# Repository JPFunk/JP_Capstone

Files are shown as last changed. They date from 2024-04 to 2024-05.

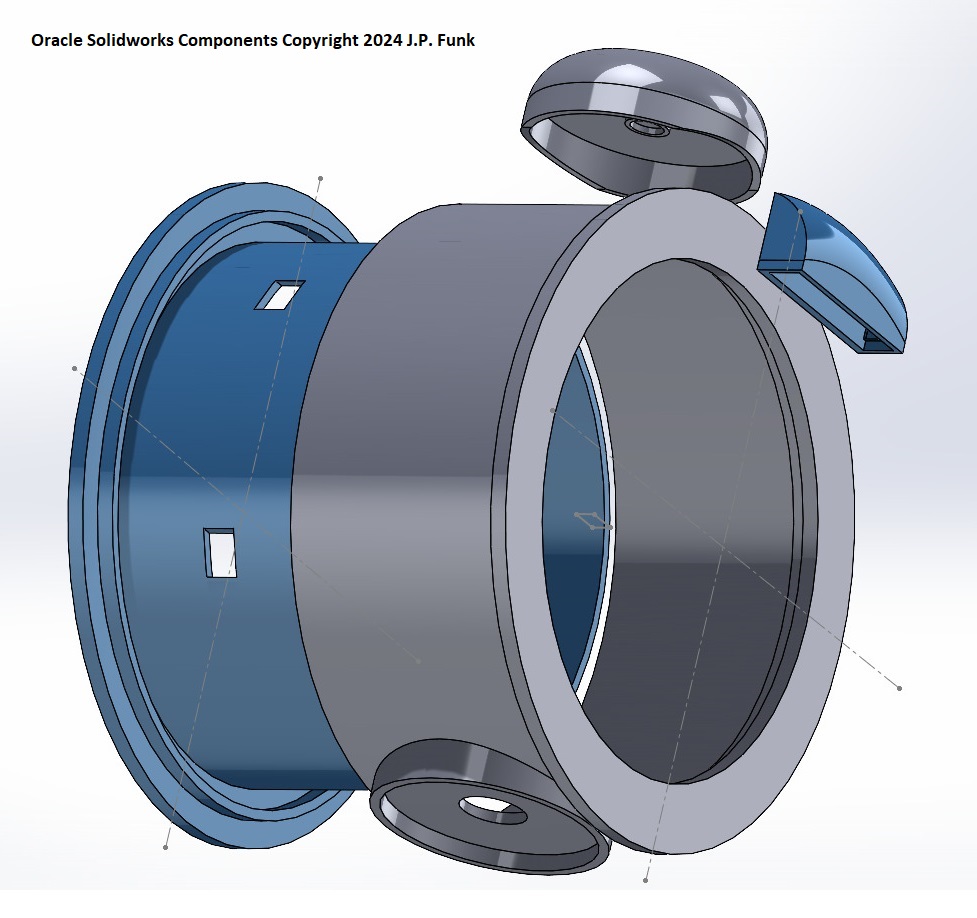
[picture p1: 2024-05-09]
JP_Capstone_Support_Files/JP_Capstone_3D/JP_Oracle_Solidworks/JP_Oracle_Assembly_Ring.JPG

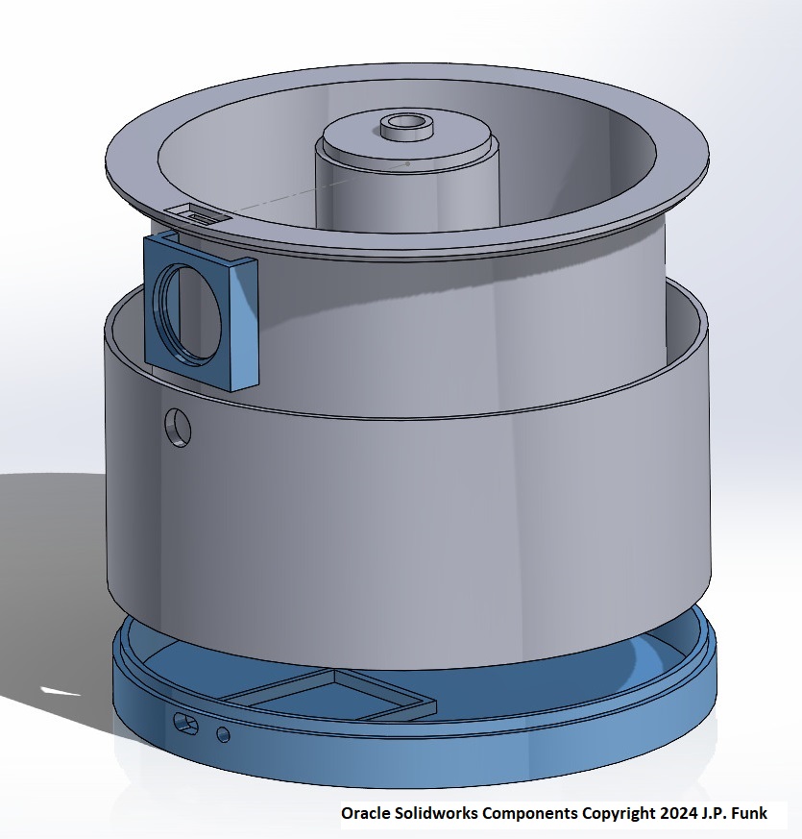
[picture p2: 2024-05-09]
JP_Capstone_Support_Files/JP_Capstone_3D/JP_Oracle_Solidworks/JP_Oracle_Assembly_Base.JPG

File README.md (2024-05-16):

# JP_Oracle_Fountain
Project completeion date: 05/16/2024

Project Motivation and Overview:
The Oracle Fountain is a IoT smart indoor water feature with Lighting and Sound components that would create Tranquil and Relaxing Ambiance for interior spaces. The fountain has 3 main modes: Waterfall feature, Crystal Ball Lighting for atmosphere (nighttime) and Sound (Looping soundscapes), Environment BME sensor with internet dashboard control/connectivity.

Ativating the modes are simple and elegant: 
The touch sensor is hidden inside the housing with just a fingertip size hole to access the button and toggles the Waterfall On Off also activating NeoPixel Waterfall panel.
The ToF has 4 levels (modes) with corresponding Neopixel (x4) color changes with each toggle:
1. Level 1- Crystal Ball on (Cyan), Crystal Ball off (Yellow)
2. Level 2- MP3 Player Tracks on (Turqoise) tracks off (Magenta)
3. Level 3- MP3 Player Volume on (Blue) tracks off (Green)
4. Level 4- Neopixels Off (for dark or stealth usage)

Control Features:
  • Waterfall pump, Music/Soundscapes and LED light show
  • Adafruit.IO Dashboard connection and functions
  • Touch button control for Waterfall and TOF: MP3 tracks, Volume and Turn off NeoPixels

Entertainment Features:
  •  MP3 player with speaker (Soundscapes)
  •  Crystal Ball with Neopixels
  •  Waterfal w/ Backlit Laser etched panel

Components: 
  • Argon processor, small board, BME sensor, ToF (Time of Flight) sensor, water pump, relay, neopixels (5) & ring, Touch Sensor, push button, MP3 w/ Speaker 
  • 3D Printed sections: Base, top ring, LED module (top) 10 parts total
  • Electrical wiring, power supply (usb)
  • Waterfall components: Tubing,  water diffusers 
  • Acrylic waterfall etched/cut panel
 
Other Information:
The Capstone design will be built to emphasis IoT features, the MVP production version will be refit with minimum E-components to accommodate a Starter Model not requiring P2 programming/connection.

Stretch Goal Features:
  • Phone App subscription for sound loops and additional content *
  • Auto and Sleep Mode
  • Patent, and produce for market

Hackster.io page

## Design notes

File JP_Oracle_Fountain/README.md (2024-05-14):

# JP_Oracle_Fountain

Project Motivation and Overview:
The Oracle Fountain is a IoT smart indoor water feature with Lighting and Sound components that would create Tranquil and Relaxing Ambiance for interior spaces. The fountain would have 3 main modes: 2 Water (high, low) Levels, Lighting for atmosphere (nighttime) and Sound (Looping soundscapes), Environment sensor with internet dashboard control/connectivity.

Minimum Features:
  • Waterfall pump,  LED light show
  • Dashboard
  • Minimum button control TOF
  • 3D Printed Housing, with one upper waterfall ring

Desired Features:
  •  MP3 player with speaker
  •  3D Printed Housing, 1 upper waterfall ring
  •  Button less interface/controls (ToF)

Stretch Goal Features:
  • Phone App subscription for sound loops and additional content *
  • Auto and Sleep Mode
  • Patent, and produce for market

Anticipated Components:
  • *TOF sensors (at least 1), small board w/ P2, water pump, relay, neopixel ring  BME
  • 3D Printed sections: Base, top ring, LED module (top)
  • Waterfall components: Tubing, connectors, water diffusers 
  • Electrical wiring, power supply (s)

Concerns and Considerations (Project Risks and Potential Mitigation's)
  •  getting TOF sensors to work properly for controls
  •  3D printed housing functional for waterfall feature. *3D design will center around 3D Printing footprint (base printing size/area)
  •  Automated modes, sleep
  •  Dashboard/bluetooth/code-red functions

Other Information:
The Capstone design will be built to emphasis IoT features, the MVP  production version will be refit with minimum E-components to accommodate a Starter Model not requiring P2 programming/connection.

Hackster.io page

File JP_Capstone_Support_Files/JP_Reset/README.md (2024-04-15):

# JP_Reset

This firmware project was created using [Particle Developer Tools](https://www.particle.io/developer-tools/) and is compatible with all [Particle Devices](https://www.particle.io/devices/).

Feel free to replace this README.md file with your own content, or keep it for reference.

## Table of Contents
- [Introduction](#introduction)
- [Prerequisites To Use This Template](#prerequisites-to-use-this-repository)
- [Getting Started](#getting-started)
- [Particle Firmware At A Glance](#particle-firmware-at-a-glance)
  - [Logging](#logging)
  - [Setup and Loop](#setup-and-loop)
  - [Delays and Timing](#delays-and-timing)
  - [Testing and Debugging](#testing-and-debugging)
  - [GitHub Actions (CI/CD)](#github-actions-cicd)
  - [OTA](#ota)
- [Support and Feedback](#support-and-feedback)
- [Version](#version)

## Introduction

For an in-depth understanding of this project template, please refer to our [documentation](https://docs.particle.io/firmware/best-practices/firmware-template/).

## Prerequisites To Use This Repository

To use this software/firmware on a device, you'll need:

- A [Particle Device](https://www.particle.io/devices/).
- Windows/Mac/Linux for building the software and flashing it to a device.
- [Particle Development Tools](https://docs.particle.io/getting-started/developer-tools/developer-tools/) installed and set up on your computer.
- Optionally, a nice cup of tea (and perhaps a biscuit).

## Getting Started

1. While not essential, we recommend running the [device setup process](https://setup.particle.io/) on your Particle device first. This ensures your device's firmware is up-to-date and you have a solid baseline to start from.

2. If you haven't already, open this project in Visual Studio Code (File -> Open Folder). Then [compile and flash](https://docs.particle.io/getting-started/developer-tools/workbench/#cloud-build-and-flash) your device. Ensure your device's USB port is connected to your computer.

3. Verify the device's operation by monitoring its logging output:
    - In Visual Studio Code with the Particle Plugin, open the [command palette](https://docs.particle.io/getting-started/developer-tools/workbench/#particle-commands) and choose "Particle: Serial Monitor".
    - Or, using the Particle CLI, execute:
    ```
    particle serial monitor --follow
    ```

4. Uncomment the code at the bottom of the cpp file in your src directory to publish to the Particle Cloud! Login to console.particle.io to view your devices events in real time.

5. Customize this project! For firmware details, see [Particle firmware](https://docs.particle.io/reference/device-os/api/introduction/getting-started/). For information on the project's directory structure, visit [this link](https://docs.particle.io/firmware/best-practices/firmware-template/#project-overview).

## Particle Firmware At A Glance

### Logging

The firmware includes a [logging library](https://docs.particle.io/reference/device-os/api/logging/logger-class/). You can display messages at different levels and filter them:

```
Log.trace("This is trace message");
Log.info("This is info message");
Log.warn("This is warn message");
Log.error("This is error message");
```

### Setup and Loop

Particle projects originate from the Wiring/Processing framework, which is based on C++. Typically, one-time setup functions are placed in `setup()`, and the main application runs from the `loop()` function.

For advanced scenarios, explore our [threading support](https://docs.particle.io/firmware/software-design/threading-explainer/).

### Delays and Timing

By default, the setup() and loop() functions are blocking whilst they run, meaning that if you put in a delay, your entire application will wait for that delay to finish before anything else can run. 

For techniques that allow you to run multiple tasks in parallel without creating threads, checkout the code example [here](https://docs.particle.io/firmware/best-practices/firmware-template/).

(Note: Although using `delay()` isn't recommended for best practices, it's acceptable for testing.)

### Testing and Debugging

For firmware testing and debugging guidance, check [this documentation](https://docs.particle.io/troubleshooting/guides/build-tools-troubleshooting/debugging-firmware-builds/).

### GitHub Actions (CI/CD)

This project provides a YAML file for GitHub, automating firmware compilation whenever changes are pushed. More details on [Particle GitHub Actions](https://docs.particle.io/firmware/best-practices/github-actions/) are available.

### OTA

To learn how to utilize Particle's OTA service for device updates, consult [this documentation](https://docs.particle.io/getting-started/cloud/ota-updates/).

Test OTA with the 'Particle: Cloud Flash' command in Visual Studio Code or the CLI command 'particle flash'!

This firmware supports binary assets in OTA packages, allowing the inclusion of audio, images, configurations, and external microcontroller firmware. More details are [here](https://docs.particle.io/reference/device-os/api/asset-ota/asset-ota/).

## Support and Feedback

For support or feedback on this template or any Particle products, please join our [community](https://community.particle.io)!

## Version

Template version 1.0.2

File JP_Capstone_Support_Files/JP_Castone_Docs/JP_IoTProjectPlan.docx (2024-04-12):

Project Name: Oracle Fountain (wellness engine) Creation Date: April 10th, 2024
Student Name: JP Funk | | | Capstone Date: May 17th

Project Motivation and Overview:

The Oracle Fountain is a IoT smart indoor water feature with Lighting, Sound & Environmental components that would create Tranquil and Relaxing Ambiance for interior spaces. The fountain would have 3 main modes: 2 Water Flow: (high, low) Levels, *Lighting for atmosphere (Multi-modes nighttime) and *Sound (Looping soundscapes), Environment sensor with internet dashboard control/connectivity.

Minimum Features:

- Waterfall pump, LED light show, BME
- Dashboard
- minimum button control
- 3D Printed Housing, with one Stage waterfall ring

Desired Features:

- MP3 player with speaker
- 2 modes water flow
- 3D Printed Housing, with 2 stages waterfall rings
- Auto and Sleep Mode
- Button less interface/controls (ToF)

Stretch Goal Features:

- Phone App (subscription for sound loops and additional content *)
- Patent, and produce for market

Anticipated Components:

- *TOF sensors (at least 1), small board w/ P2, water pump, relay, neopixel ring *OLED, BME, *Encoder
- 3D Printed sections: Base, lower ring, top ring, LED module (top)
- Waterfall components: Tubing, connectors, water diffusers
- Electrical wiring, power supply (s)

Concerns and Considerations (Project Risks and Potential Mitigation's)

- Getting TOF sensors to work properly for controls
- 3D printed housing functional for waterfall feature. *3D design will center around 3D Printing footprint (base printing size/area)
- Automated modes, sleep
- Dashboard/bluetooth/code-red functions

Other Information:

*OLED may/may not be used depending on design build.

The Capstone design will be built to emphasis IoT features, the MVP production version will be refit with minimum E-components to accommodate a Starter Model not requiring P2 programming/connection.

Project Implementation Timeline:
Tasks | 12-APR | 19-APR | 26-APR | 3-May | 10-May | 17-May
Project Plan | X | | | | | Presentation
JP_Capstone Oracle Fountain Daily work/production will logged on Calendar | Submit Project plan summary | Prototype case with TOF, starting code | Design and build 3D Waterfall housing | Write/implement code, testing, Debug | Create: Presentation Media, Video, Hackster.io etc. | Demo: Presentation Hackster Video Q/A
Hours per week/
Capstone Presentation | | | | | | X

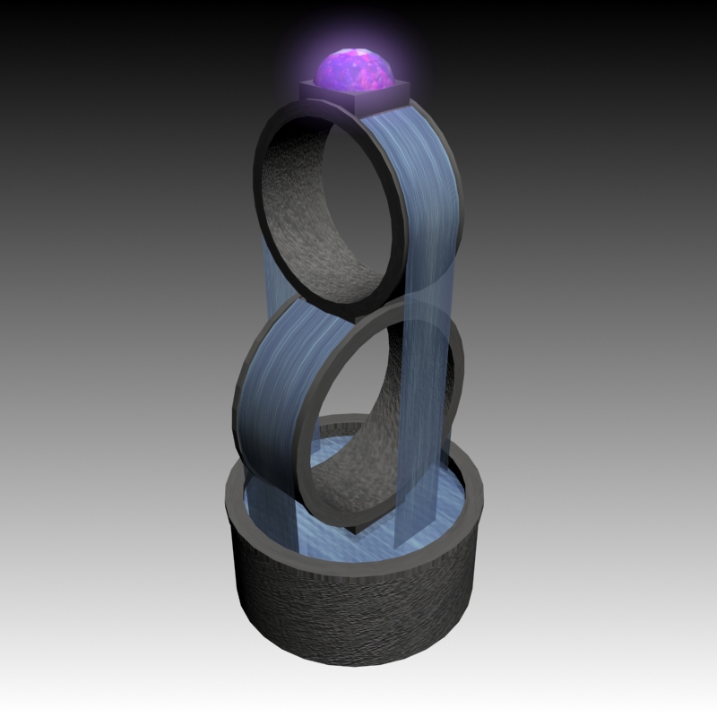
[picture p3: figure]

3D Render simple visualization concept: The base reservoir section (Bottom) will be designed to house the electrical components of the project with designated channels in the base (bottom or a specific section of the side) to house the processor and board.

ToF, OLED, BME, Encoder etc. will be implemented inside electrical gaps/channels residing between the outer face/shell and water shell wall with cut outs (custom installation mounts) for these features. Similar implementation will be used to run the water tubing and wiring through the rings for LED, OLED, BME features etc.

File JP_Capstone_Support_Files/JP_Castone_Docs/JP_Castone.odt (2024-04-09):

JP Funk IoT Deep Dive Boot Camp Capstone Project submission: Oracle Fountain

The Oracle Fountain is a IoT smart indoor water feature with Lighting and Sound components that would create Tranquil and Relaxing Ambiance for interior spaces.

The fountain would have 3 main modes: 2 Water Pump/Speed (high, low) Levels, Lighting for atmosphere (nighttime) and Sound (Looping soundscapes).

The interface would be Elegant and simple: IR Range and Motion Sensors requiring no buttons or switches on the front panel that would detect and use proximity for activating the features.

Other Sensors could be implemented for environmental detection and awareness.

*The Sound module would ideally be loops that would require little bit of memory and would be in first Gen simplified into a few modes:

1. Bells/Gong

2. Chimes

3. Bowls

*4. Tongue Drum

The physical portion of the fountain would be build up from 3 main 3D Printed sections:

The Water/pump & Electronics Basin, the 1st vertical ring and a 2nd vertical ring (stacked up on top of each other).

The Oracle Fountain would sit in a room/space, offer 2 levels (high, low) of water flow, a nighttime light show and Looping soundscapes. *It could be remotely monitored and activated (either through Adafruit, BT and/or Node-Red etc.). The goal is to produce these as MVP for my entrepreneurial biz in short run (per customer order) then move up to larger production if product became an in demand commodity.

The Oracle has been an idea(concept) initially thought of a year ago during the Santa Fe Creative Startups 6 week class. A sound system prototype was built (Speaker box) and then evolved to a water feature with lighting. The sound system might later be implemented as a BlueTooth app with many sound and atmosphere features.

Can Do’s: Water Pump, LED (NeoPixels), motion sensor w/code- 3D Printing

Have not done yet: A very sophisticated Customized 3D Printed system w/ many watertight seals at connection joints, wiring, tubing, encased electronics & sound system.

IR sensors for touch less control (with code)- controlling water pump, LED and sound system integration with Loops. Possible room/environment observation.

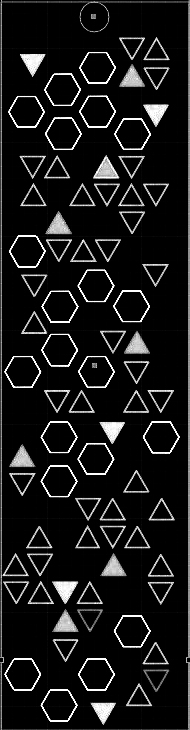
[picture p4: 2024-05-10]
JP_Capstone_Support_Files/JP_Capstone_3D/3D_Maps/JP_Oracle_WaterPane_Alpha.jpg

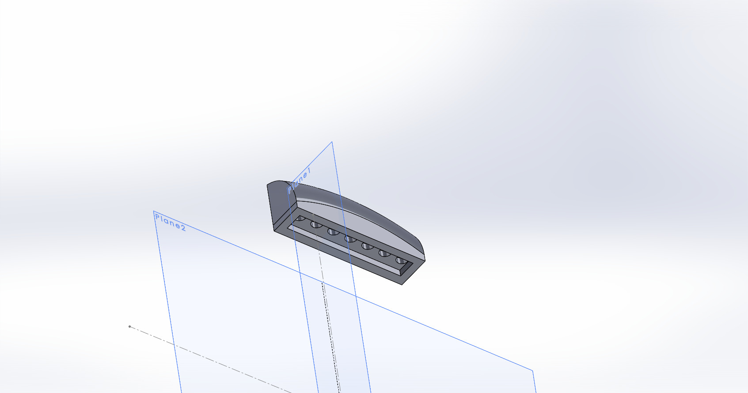
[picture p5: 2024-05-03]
JP_Capstone_Support_Files/JP_Capstone_3D/JP_Oracle_Solidworks/JP_Oracle_Top_Water_Shroud_Front.JPG

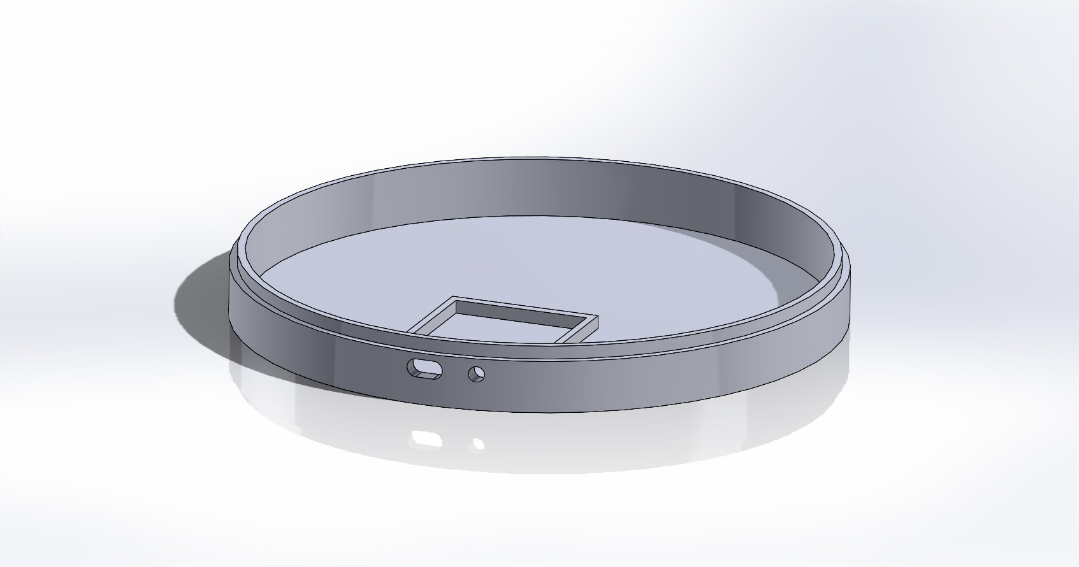
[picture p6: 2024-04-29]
JP_Capstone_Support_Files/JP_Capstone_3D/JP_Oracle_Solidworks/JP_Oracle_EBase.JPG

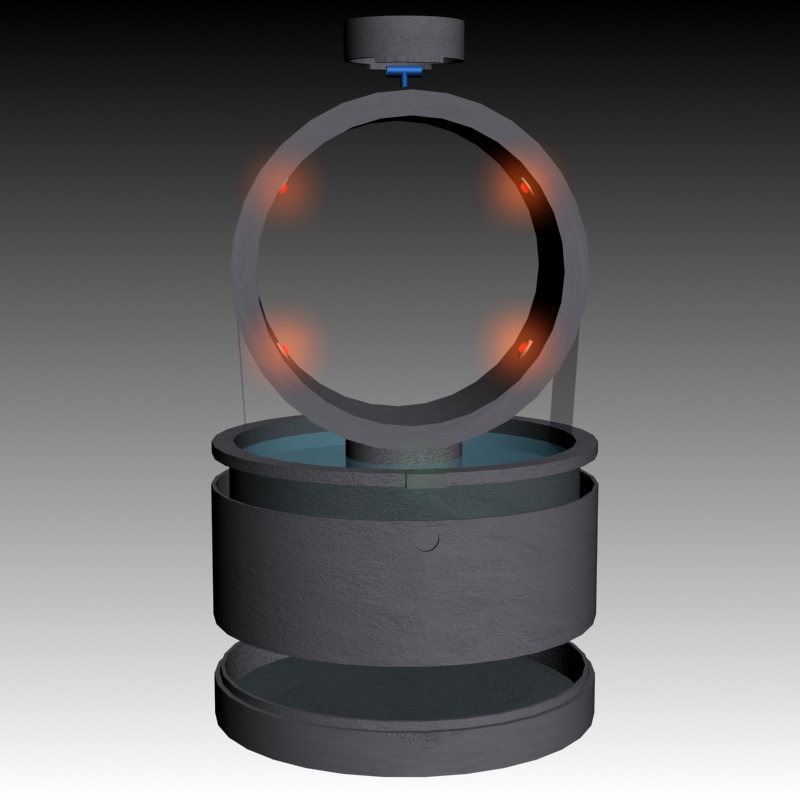
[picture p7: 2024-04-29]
JP_Capstone_Support_Files/JP_Capstone_3D/JP_Oracle_Explode_View.jpg

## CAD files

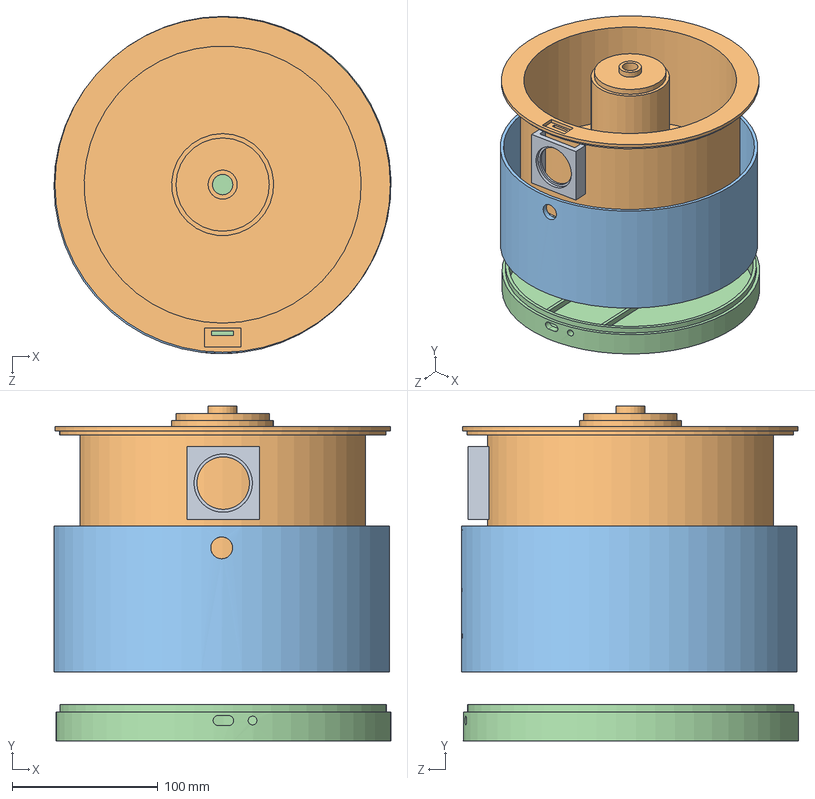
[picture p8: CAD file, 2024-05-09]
JP_Capstone_Support_Files/JP_Capstone_3D/JP_Oracle_Solidworks/JP_Oracle_Assembly_Base.SLDASM
231.1 x 229.7 x 231.3 mm
JP_Oracle_EBase
JP_Oracle_Base_Ring
JP_Oracle_Water_Basin
JP_Oracle_Speaker_Ring

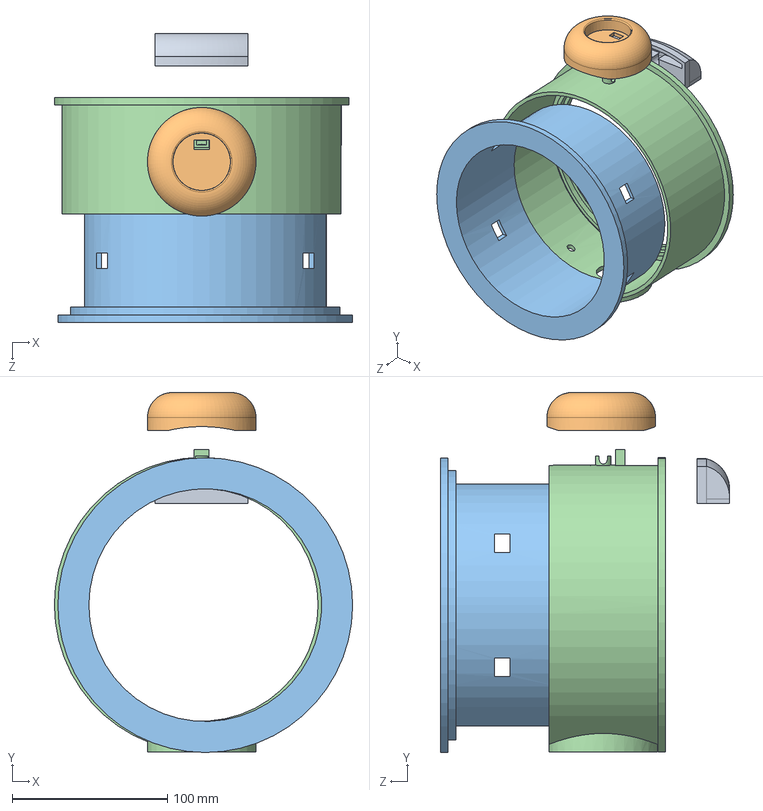
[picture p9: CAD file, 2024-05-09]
JP_Capstone_Support_Files/JP_Capstone_3D/JP_Oracle_Solidworks/JP_Oracle_Assembly_Ring.SLDASM
192.3 x 232.1 x 186.4 mm
JP_Oracle_Top_Ring_Outer
JP_Oracle_Top_Ring_inner
JP_Oracle_Top_Crystal
JP_Oracle_Top_Water_ShroudV2

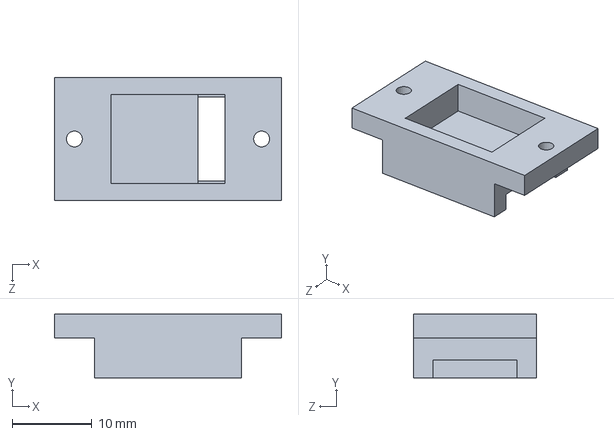
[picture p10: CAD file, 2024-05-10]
JP_Capstone_Support_Files/JP_Capstone_3D/JP_Oracle_Solidworks/JP_BME_Holder.SLDPRT
28.5 x 8.00 x 15.5 mm

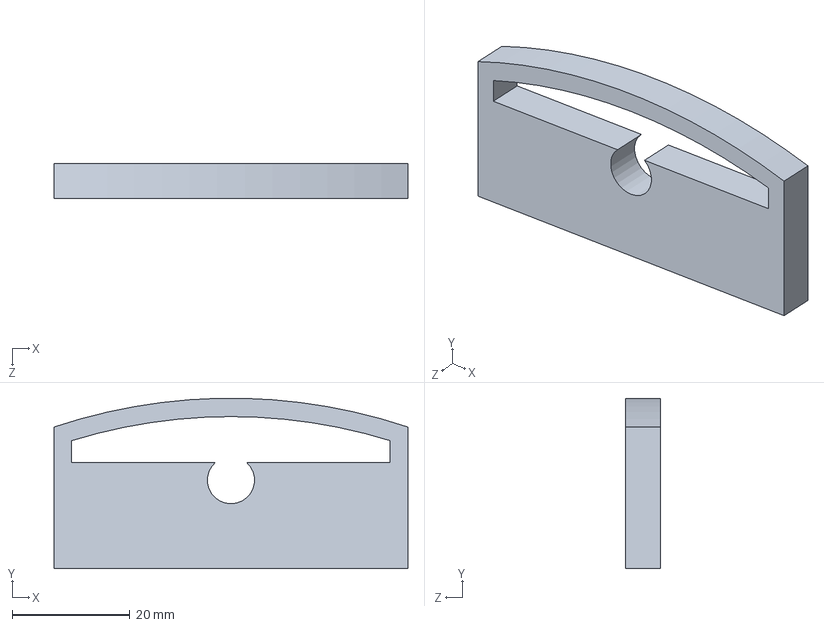
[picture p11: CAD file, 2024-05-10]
JP_Capstone_Support_Files/JP_Capstone_3D/JP_Oracle_Solidworks/JP_Oracle_Top_Water_ShroudV2_Extender.SLDPRT
60.0 x 28.9 x 6.00 mm

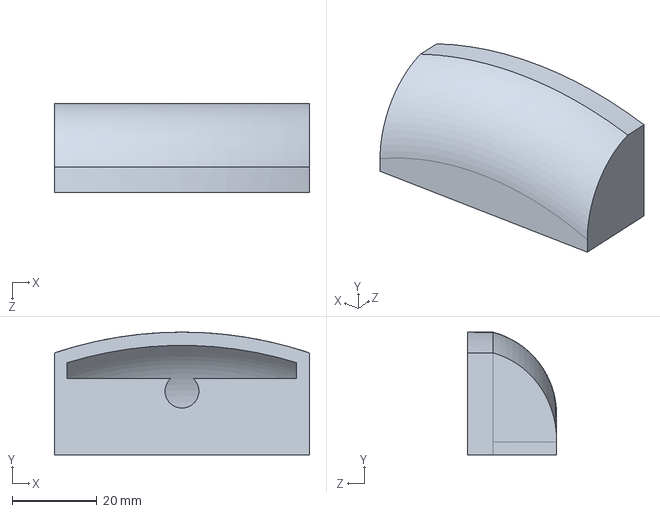
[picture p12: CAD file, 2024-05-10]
JP_Capstone_Support_Files/JP_Capstone_3D/JP_Oracle_Solidworks/JP_Oracle_Top_Water_ShroudV2.SLDPRT
60.0 x 28.9 x 21.0 mm

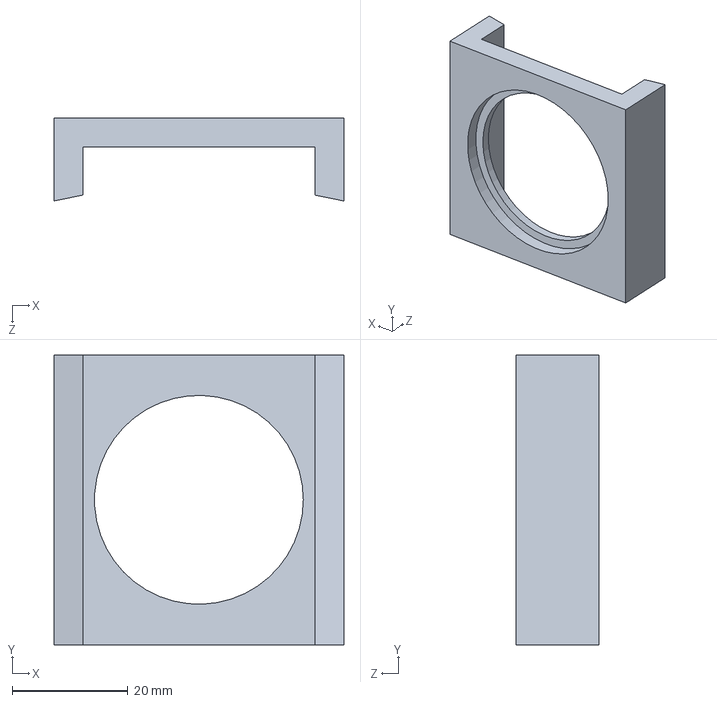
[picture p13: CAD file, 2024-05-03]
JP_Capstone_Support_Files/JP_Capstone_3D/JP_Oracle_Solidworks/JP_Oracle_Speaker_Ring.SLDPRT
50.0 x 50.0 x 14.3 mm

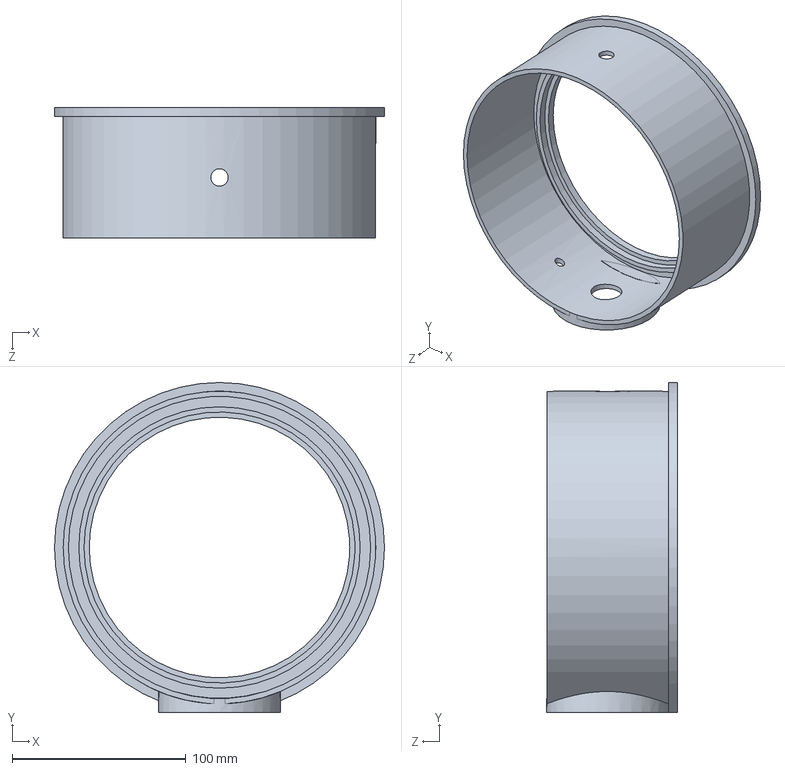
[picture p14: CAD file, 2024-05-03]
JP_Capstone_Support_Files/JP_Capstone_3D/JP_Oracle_Solidworks/JP_Oracle_Top_Ring_Outer1.SLDPRT
190.0 x 190.0 x 75.1 mm

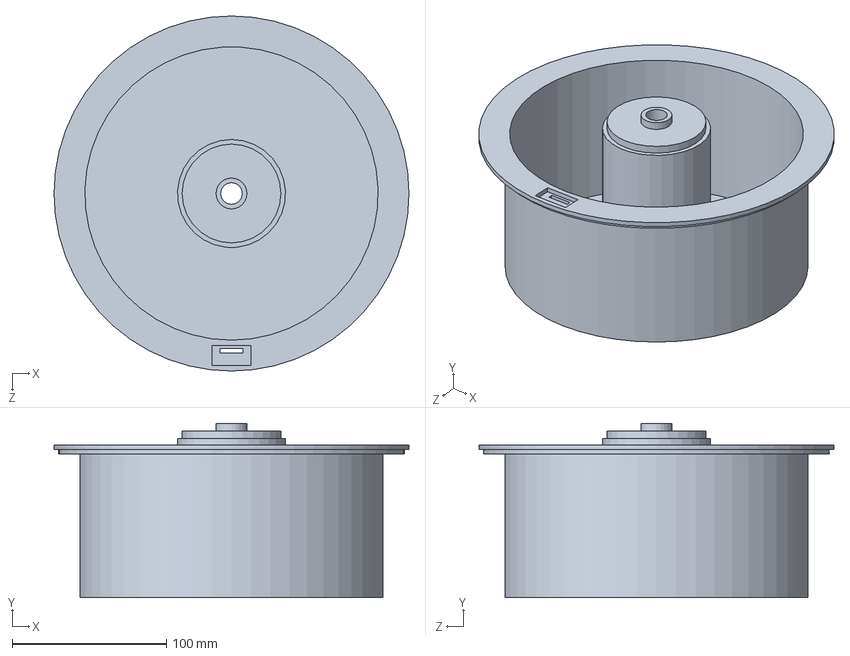
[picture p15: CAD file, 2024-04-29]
JP_Capstone_Support_Files/JP_Capstone_3D/JP_Oracle_Solidworks/JP_Oracle_Water_Basin.SLDPRT
230.0 x 113.0 x 230.0 mm

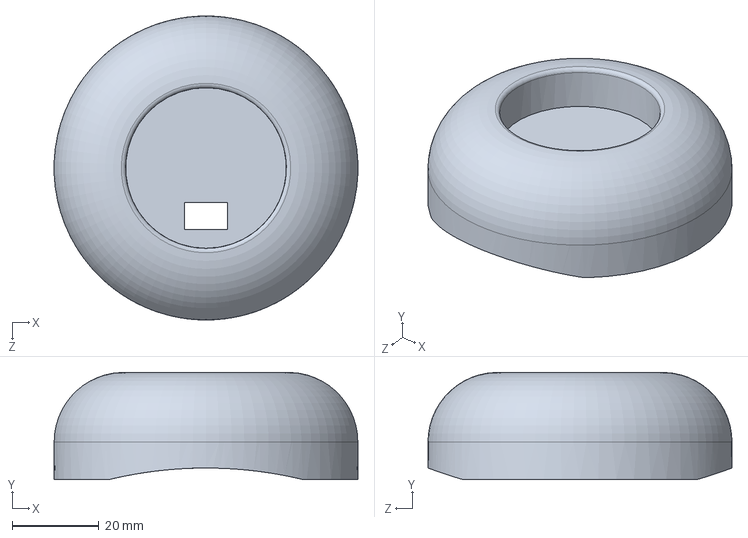
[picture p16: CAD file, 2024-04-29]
JP_Capstone_Support_Files/JP_Capstone_3D/JP_Oracle_Solidworks/JP_Oracle_Top_Crystal.SLDPRT
70.0 x 24.6 x 70.0 mm

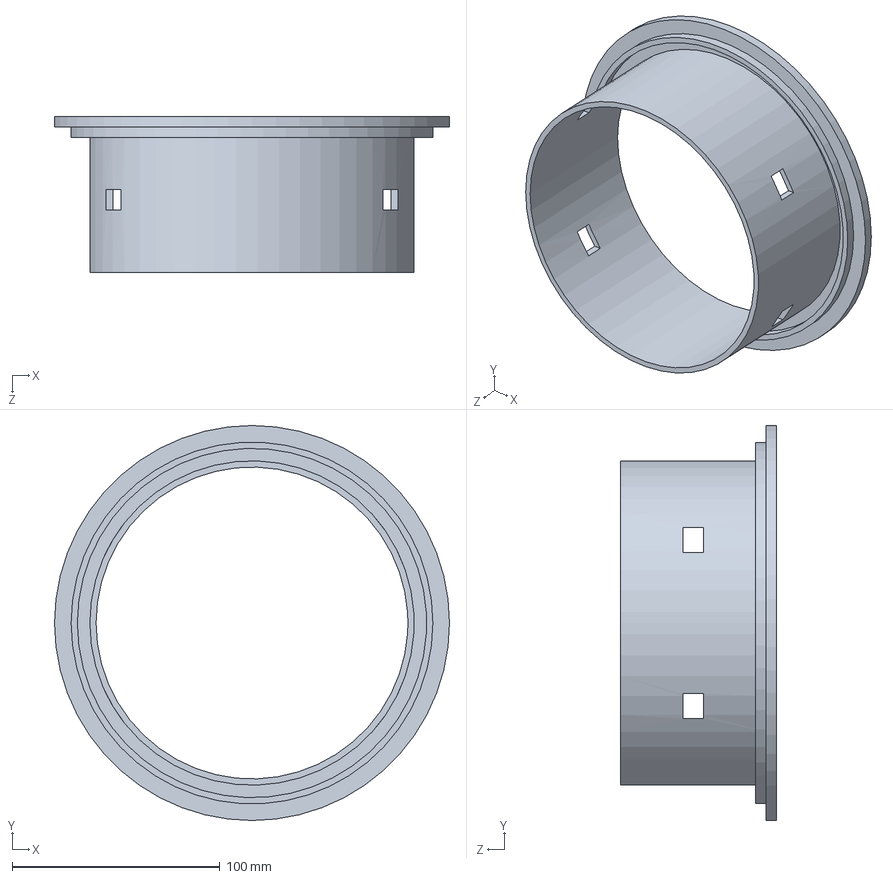
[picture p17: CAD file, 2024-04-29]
JP_Capstone_Support_Files/JP_Capstone_3D/JP_Oracle_Solidworks/JP_Oracle_Top_Ring_inner.SLDPRT
190.0 x 190.0 x 75.0 mm

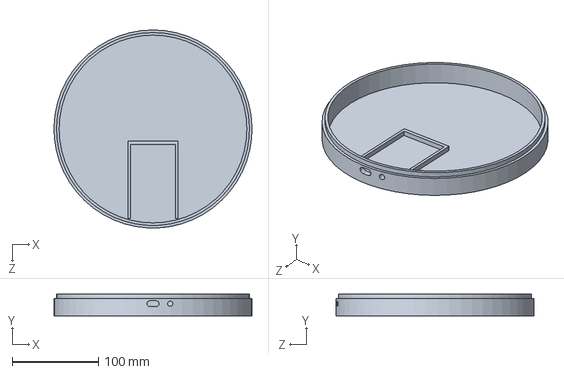
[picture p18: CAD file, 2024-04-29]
JP_Capstone_Support_Files/JP_Capstone_3D/JP_Oracle_Solidworks/JP_Oracle_EBase.SLDPRT
229.9 x 25.0 x 230.0 mm

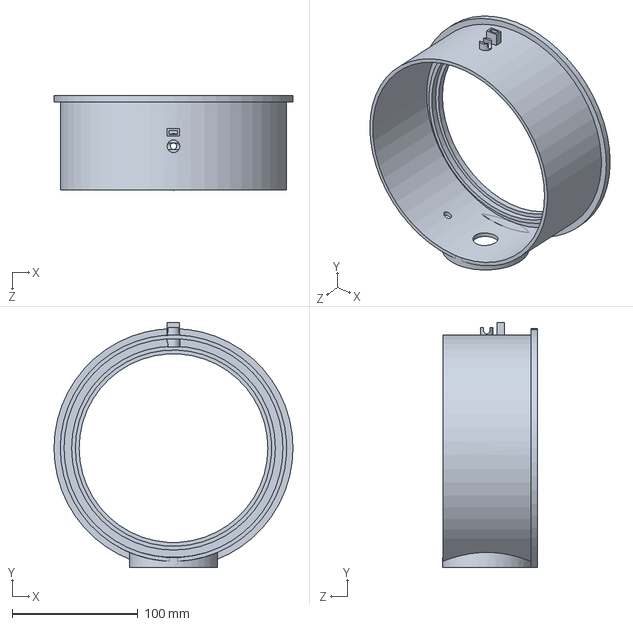
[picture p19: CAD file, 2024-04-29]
JP_Capstone_Support_Files/JP_Capstone_3D/JP_Oracle_Solidworks/JP_Oracle_Top_Ring_Outer.SLDPRT
190.0 x 195.0 x 75.1 mm

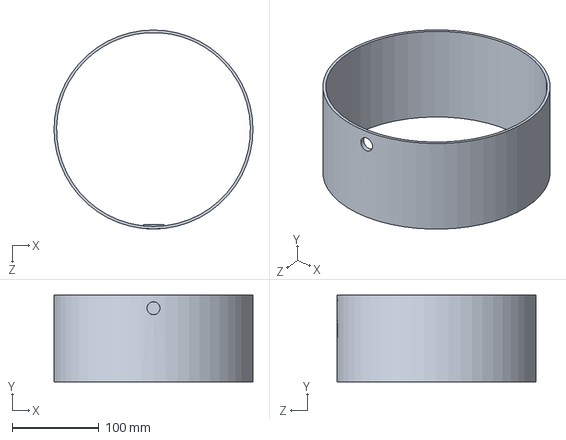
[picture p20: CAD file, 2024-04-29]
JP_Capstone_Support_Files/JP_Capstone_3D/JP_Oracle_Solidworks/JP_Oracle_Base_Ring.SLDPRT
230.0 x 100.0 x 230.0 mm

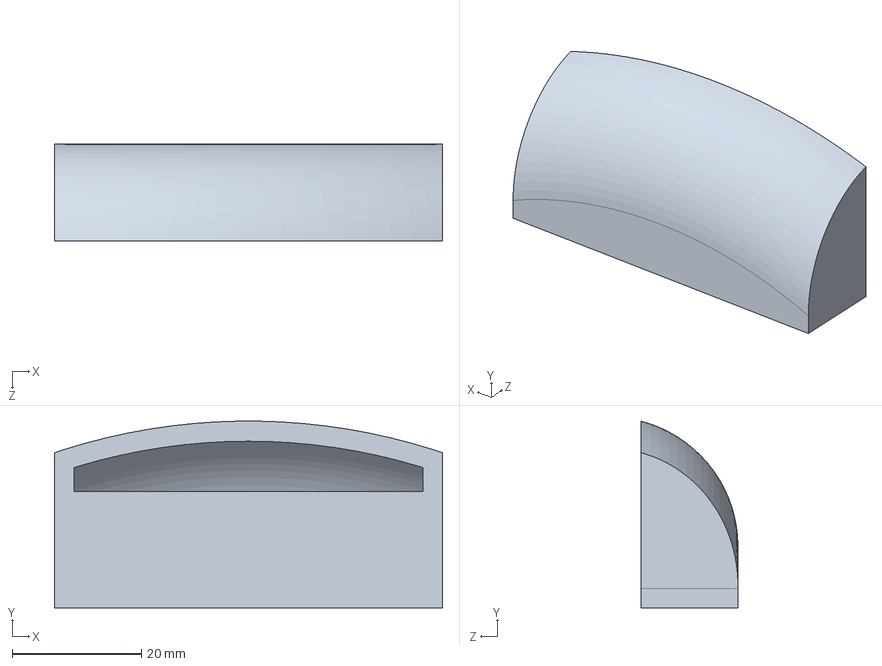
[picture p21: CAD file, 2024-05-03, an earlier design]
JP_Capstone_Support_Files/JP_Capstone_3D/JP_Oracle_Solidworks/JP_Oracle_Top_Water_Shroud.SLDPRT
60.0 x 28.9 x 15.0 mm

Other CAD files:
JP_Capstone_Support_Files/JP_Capstone_3D/JP_Oracle_Solidworks/JP_BME_Holder.STL
JP_Capstone_Support_Files/JP_Capstone_3D/JP_Oracle_Solidworks/JP_Oracle_Assembly_Base.STL
JP_Capstone_Support_Files/JP_Capstone_3D/JP_Oracle_Solidworks/JP_Oracle_Assembly_Ring.STL
JP_Capstone_Support_Files/JP_Capstone_3D/JP_Oracle_Solidworks/JP_Oracle_Base_Ring.STL
JP_Capstone_Support_Files/JP_Capstone_3D/JP_Oracle_Solidworks/JP_Oracle_EBase.STL
JP_Capstone_Support_Files/JP_Capstone_3D/JP_Oracle_Solidworks/JP_Oracle_Speaker_Ring.STL
JP_Capstone_Support_Files/JP_Capstone_3D/JP_Oracle_Solidworks/JP_Oracle_Top_Crystal.STL
JP_Capstone_Support_Files/JP_Capstone_3D/JP_Oracle_Solidworks/JP_Oracle_Top_Ring_Outer.STL
JP_Capstone_Support_Files/JP_Capstone_3D/JP_Oracle_Solidworks/JP_Oracle_Top_Ring_Outer1.STL
JP_Capstone_Support_Files/JP_Capstone_3D/JP_Oracle_Solidworks/JP_Oracle_Top_Ring_inner.STL
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

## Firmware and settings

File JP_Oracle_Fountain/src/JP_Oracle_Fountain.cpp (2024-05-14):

/* 
 * Project JP_Oracle_Fountain
 * Author: JP Funk
 * Date: 05/13/2024 Monday update Finished!
 * For comprehensive documentation and examples, please visit:
 * https://docs.particle.io/firmware/best-practices/firmware-template/
 */

// Include Particle Device OS APIs
#include "Particle.h"
#include "Adafruit_VL53L0X.h"
#include <SPI.h>
#include "credentials.h"
#include "Adafruit_MQTT.h"
#include "Adafruit_MQTT/Adafruit_MQTT_SPARK.h"
#include "Adafruit_MQTT/Adafruit_MQTT.h"
#include "Adafruit_BME280.h"
#include "DFRobotDFPlayerMini.h"
#include "IoTClassroom_CNM.h"
#include "IoTTimer.h"
#include "math.h"
#include "Button.h"
#include "neopixel.h"
#include "Colors.h"

// DFRobotMP3 Player
DFRobotDFPlayerMini myDFPlayer;
Button nextButton(D0);
unsigned int lastSong;
int track;
bool startStop, volOnOff, mp3Dash, prevMp3Dash;

// TOF VL53LOX Sensor
Adafruit_VL53L0X lox = Adafruit_VL53L0X();
int TOF;
bool targetLoc0, targetLoc1, targetLoc2, targetLoc3, targetLoc4;
bool prevTargetLoc1, prevTargetLoc2, prevTargetLoc3;
bool position;
unsigned int rangeTime = 250;
void targetButton1();
void targetButton2();
void targetButton3();

// Reset Button
int8_t RST;
const int RESETBUTTON (RST);
int resetBtn, lastInterval;

//bool buttonState1;
void buttonisClicked();
bool changed, buttonState;

// Touch Sensor
Button PUMPBUTTON (D3);
void WATERPUMP ();

// Neopixel
const int PIXELCOUNT = 5;
int i, pixelAddr, colorCount, hold;
bool neoOnOff, blackOnOff;
void pixelFill(int start, int end, int color);
void targetRange();
Adafruit_NeoPixel pixel(PIXELCOUNT, D2, WS2812B);

// Water Pump
const int PUMPIN = D7;
float  pubValue;
bool  pumpDash;

// Millis Timer
unsigned int beginTime;
unsigned int duration;

// Date and Time String
String DateTime, TimeOnly; // String variable for Date and Time

// Adafruit BME
Adafruit_BME280 bme;
const char degree = 0xf8;
const int delayTime =1000;
bool status;
int hexAddress, startime;
float tempC, pressPA, humidRH, tempF, inHG;
void BMEValues();

void watchdogHandler() {
// Do as little as possible in this function , preferably just a reset
System.reset (RESET_NO_WAIT);
}
TCPClient TheClient;
Adafruit_MQTT_SPARK mqtt(&TheClient,AIO_SERVER,AIO_SERVERPORT,AIO_USERNAME,AIO_KEY); 
// Setup the MQTT client class by passing in the WiFi client and MQTT server and login details. 
Adafruit_MQTT_Publish tempFeed = Adafruit_MQTT_Publish(&mqtt,AIO_USERNAME"/feeds/tempFeed");
Adafruit_MQTT_Publish pressFeed = Adafruit_MQTT_Publish(&mqtt,AIO_USERNAME"/feeds/pressFeed");
Adafruit_MQTT_Publish humidFeed = Adafruit_MQTT_Publish(&mqtt,AIO_USERNAME"/feeds/humidFeed");
Adafruit_MQTT_Subscribe pumpFeed = Adafruit_MQTT_Subscribe(&mqtt,AIO_USERNAME"/feeds/pumpFeed");
Adafruit_MQTT_Subscribe buttonFeed = Adafruit_MQTT_Subscribe(&mqtt,AIO_USERNAME"/feeds/buttononoff"); 
Adafruit_MQTT_Subscribe MP3Feed = Adafruit_MQTT_Subscribe(&mqtt,AIO_USERNAME"/feeds/MP3Feed");
Adafruit_MQTT_Subscribe PixelRingFeed = Adafruit_MQTT_Subscribe(&mqtt,AIO_USERNAME"/feeds/PixelRingFeed");  
/************Declare Functions*************/
void MQTT_connect();
bool MQTT_ping();
// Let Device OS manage the connection to the Particle Cloud
void getConc ();
 
SYSTEM_MODE(SEMI_AUTOMATIC);

#if (PLATFORM_ID == 32)
#endif
#define PIXEL_TYPE WS2812B
const int PIXEL_COUNT =12;
Adafruit_NeoPixel strip(PIXEL_COUNT, D12, WS2812B);
void rainbowRing(uint8_t hold);
uint32_t Wheel(byte WheelPos);
IoTTimer neoTimer;
IoTTimer locTimer;
bool repeatCycle, pixelDash, prevPixelDash;
void pixelRingOff();
SYSTEM_THREAD(ENABLED);

// View logs with CLI using 'particle serial monitor --follow'
SerialLogHandler logHandler(LOG_LEVEL_INFO);

void setup() {
waitFor(Serial.isConnected, 5000);
Serial.begin(115200);
Serial1.begin(9600);
delay(1000);

Wire.begin(); // ToF start sequence
// New Neo Code
strip.begin();
strip.show(); // Initialize all pixels to 'off'
repeatCycle = TRUE;
neoTimer.startTimer(20);

if (!lox.begin()) {
  Serial.println(F("Failed to boot VL53L0X"));
  while(1);
}
// wait until serial port opens for native USB devices
while (! Serial) {
  delay(1);
}
Serial.println("Adafruit VL53L0X test");
if (!lox.begin()) {
  Serial.println(F("Failed to boot VL53L0X"));
  while(1);
}
 
// Connect to Internet but not Particle Cloud
WiFi.on();
WiFi.connect();
  while(WiFi.connecting()) {
  Serial.printf(".");
  }
Serial.printf("\n\n");
// Setup MQTT subscription
mqtt.subscribe(&buttonFeed);
mqtt.subscribe(&pumpFeed);
mqtt.subscribe(&MP3Feed);
mqtt.subscribe(&PixelRingFeed);

// Particle Time
Particle.connect;  
Time.zone (-7); // MST = -7, MDT = -6
Particle.syncTime (); // Sync time with Particle Cloud

// Button
pinMode(RESETBUTTON, INPUT);
//Pump Pin
pinMode (PUMPIN, OUTPUT);

// NeoPixel Set Up
pixel.begin ();
pixel.setBrightness (64); // bri is a value 0 - 255
pixel.show (); // initialize all off

//DFRobotMP3Player
if (!myDFPlayer.begin(Serial1)) {  //Use softwareSerial to communicate with mp3.
  Serial.printf("Unable to begin:\n");
  Serial.printf("1.Please recheck the connection!\n");
  Serial.printf("2.Please insert the SD card!\n");
  while(true);
}
Serial.printf("DFPlayer Mini online.\n");
myDFPlayer.volume(17);  //Set volume value. From 0 to 30
myDFPlayer.loop(1);  //Play the first mp3
// Millis Startime
beginTime = millis();
lastInterval = millis();

// initialize BME
status = bme.begin(0x76);
  if (status==false);{
  //Serial.printf("BME280 at address 0x%02X failed to start\n", 0x76); // Adafruit_BME280 bme code
  }
startime = millis();
}

// loop() runs over and over again, as quickly as it can execute.
void loop() {
WATERPUMP();
targetButton1();
targetButton2();
targetButton3();
locTimer.startTimer(10000);
 
 // TOF Ranging functions
VL53L0X_RangingMeasurementData_t measure;
lox.rangingTest(&measure, false); // pass in 'true' to get debug data printout!
targetRange(); // Neopixel VOID function int for target ranges
//Serial.printf("measure data %i\n",measure.RangeMilliMeter);
if (measure.RangeStatus != 5) {  // phase failures have incorrect data
  if(measure.RangeMilliMeter <= 70){
    targetLoc1 = TRUE;
    targetLoc2 = FALSE;
    targetLoc3 = FALSE;
    targetLoc4 = FALSE;
    targetLoc0 = FALSE;
  // Serial.printf("targetPos 1%i\n", targetLoc1);
  }
  else if(measure.RangeMilliMeter > 70 && measure.RangeMilliMeter < 150){
    targetLoc2 = TRUE;
    targetLoc1 = FALSE; 
    targetLoc3 = FALSE;
    targetLoc4 = FALSE;
    targetLoc0 = FALSE;
  // Serial.printf("targetPos 2%i\n", targetLoc2);
  }
  else if(measure.RangeMilliMeter > 150 && measure.RangeMilliMeter < 230){
    targetLoc3 = TRUE;
    targetLoc1 = FALSE; 
    targetLoc2 = FALSE;
    targetLoc4 = FALSE;
    targetLoc0 = FALSE;
    //Serial.printf("targetPos 3%i\n", targetLoc3);
  }
  else if (measure.RangeMilliMeter > 230 && measure.RangeMilliMeter < 400){
    targetLoc4 = TRUE;
    targetLoc1 = FALSE; 
    targetLoc2 = FALSE; 
    targetLoc3 = FALSE;
    targetLoc0 = FALSE;
    //Serial.printf("targetPos 0%i\n", targetLoc0);
  }  
  else if  (measure.RangeMilliMeter > 400){ //Reset 7000
    locTimer.startTimer(10000);
    targetLoc0 = TRUE;
    targetLoc1 = FALSE; 
    targetLoc2 = FALSE; 
    targetLoc3 = FALSE;
    targetLoc4 = FALSE;
    //Serial.printf("targetPos 0%i\n", targetLoc0);
  }
} 

MQTT_connect();
MQTT_ping();
BMEValues();

// Adafruit Dashboard Button Functions
Adafruit_MQTT_Subscribe *subscription;
while ((subscription = mqtt.readSubscription(100))) {
  if (subscription == &buttonFeed) {
    resetBtn = atoi((char *)buttonFeed.lastread);
    Serial.printf("buttonFeed%i\n", resetBtn);
    }
  if (subscription == &pumpFeed) {
    pumpDash = atoi((char *)pumpFeed.lastread);
    Serial.printf("pumpFeed%i\n", pumpDash); //subValue
    }
  if (subscription == &MP3Feed) {
    mp3Dash = atoi((char *)MP3Feed.lastread);
    Serial.printf("MP3Feed%i\n", mp3Dash);
    targetButton2();
    }
  if (subscription == &PixelRingFeed) {
    pixelDash = atoi((char *)PixelRingFeed.lastread);
    Serial.printf("PixelRingFeed%i\n", pixelDash);
    }
  }

// Adafruit MQTT Publish functions----------------------------------------------
Adafruit_MQTT_Publish *publish;
static unsigned int last;
if ((millis()-last)>10000 ) 
  if(mqtt.Update()) {
    tempFeed.publish(tempF);
    pressFeed.publish(inHG);
    humidFeed.publish(humidRH);
    last = millis();
    }
    if (resetBtn) {
    System.reset(RESET_NO_WAIT);
  }
} //End Void Loop Functions

void BMEValues(){
  DateTime =Time.timeStr(); // Current Date and Time from Particle Time class
  TimeOnly =DateTime.substring (11,19); // Extract the Time from the DateTime String
  // BME functions with OLED display
  tempC = bme.readTemperature();
  tempF = map (tempC,0.0,100.0,32.0,212.0);
  pressPA = bme.readPressure();
  inHG = pressPA / 3386.0;
  humidRH = bme.readHumidity();  
}

void WATERPUMP (){
   // Pump Button
  if(PUMPBUTTON.isClicked()) {
    buttonState =!buttonState;
    pumpDash = !pumpDash;
  }
  if (buttonState || pumpDash){
    digitalWrite (PUMPIN, HIGH);
    pixel.setBrightness (128);
    pixelFill(4,4, turquoise);
    // Serial.printf("Pump Button On\n");
    } 
    else {
      digitalWrite (PUMPIN, LOW);
      pixelFill(4,4, black);
      // Serial.printf("Pump OFF \n");
    }
  }

// VOID Functions Neopixel
void pixelFill(int start, int end, int color) {
 int i;
 for (i=start; i<=end; i++){
 pixel.setPixelColor (i, color); // hexadecimal color
 }
  pixel.show (); // nothing changes until show ()
}

// TOF Level 1 Neopixel Range 0-70mm w/ Dashboard button OnOff togle Function
void targetButton1(){
  if ((targetLoc1 != prevTargetLoc1) || pixelDash != prevPixelDash) { //(targetLoc1 != prevTargetLoc1)
    if ((targetLoc1 == TRUE) || pixelDash == TRUE){
      neoOnOff= !neoOnOff;
      if (neoOnOff) {
        repeatCycle = TRUE;
        rainbowRing(20);
       // Serial.printf("Neo Ring On%i\n",targetLoc1);
       // Serial.printf("Neo Ring Dash On%i\n",pixelDash);
      } 
      else {
       // Serial.printf("Neo Ring Off%i\n",targetLoc1);
       // Serial.printf("Neo Ring Dash Off%i\n",pixelDash);
        strip.clear();
        strip.show();
      }
    }
    prevTargetLoc1 = targetLoc1;
    prevPixelDash = pixelDash;
  }
}

// TOF Level 2 MP3 TOF Range 70-150mm  w/ Dashboard button OnOff togle Function
void targetButton2(){
  if ((targetLoc2 != prevTargetLoc2) || mp3Dash != prevMp3Dash) {
     Serial.printf("targetLoc 2 changed%i\n",targetLoc2);
    if ((targetLoc2 == TRUE) || mp3Dash == TRUE) {
      startStop = !startStop;
      if (startStop){
        myDFPlayer.play(track%6+1);
        // Serial.printf("MP3 On%i\n",targetLoc2);
        // Serial.printf("MP3 Dash On%i\n",mp3Dash);
      } 
      else {
        myDFPlayer.stop();
        // Serial.printf("MP3 Off%i\n",targetLoc2);
        // Serial.printf("MP3 Dash Off%i\n",mp3Dash);
        track++;
      }
    }
    prevTargetLoc2 = targetLoc2; // previous location
    prevMp3Dash = mp3Dash;
  }
}

// TOF Level 3 MP3 Volume old Range 150-230mm
void targetButton3(){
  if (targetLoc3 != prevTargetLoc3) {
    if (targetLoc3 == TRUE){
      //Serial.printf("%i,%i\n", targetLoc3, prevTargetLoc3);
      volOnOff = !volOnOff;
      if (volOnOff){
        myDFPlayer.volume(28);
        // Serial.printf("Volume On%i\n",targetLoc3);
      } 
      else {
        myDFPlayer.volume(0);
        //Serial.printf("Volume Off%i\n",targetLoc3);
      }
      pixel.show();
    }
    prevTargetLoc3 = targetLoc3;
  }
}

 // Neopixel activation with TOF Ranges
void targetRange() {
  if(targetLoc1 || pixelDash){   //Neopixel TOF  & Dashboard location 1  NeoPixel Ring OnOFF
    if (neoOnOff){
      pixelFill(0,3,teal);
    }
    else {
      pixelFill(0,3,orange);
      strip.clear();
      strip.show();
    }
  }

  if(targetLoc2 || mp3Dash){    //Neopixel TOF & Dashboard location 2  MP3 Tracks OnOFF
    if (startStop){
      pixelFill(0,3,turquoise);
    }
    else {
      pixelFill(0,3,magenta);
    }
    pixel.show();
  }

  if(targetLoc3){   //Neopixel TOF location 3  MP3 Volume OnOFF
    if (volOnOff){
      pixelFill(0,3,blue);
    }
    else {
      pixelFill(0,3,lime);
    }
    pixel.show();
  }

  if(targetLoc4){    //Neopixel TOF location 0 Turn Off Black
    blackOnOff =!blackOnOff;
    if (blackOnOff){
      pixelFill(0,3, black);
    }
  }

  if(targetLoc0){    //Neopixel TOF reset
    //rainbowRing(20);
    if (neoOnOff == FALSE){
      strip.show();
      strip.clear();
      }
    if(locTimer.isTimerReady()){
      pixelFill(0,3, black);
    }
  }
}

// Rainbow Ring NeoPixel Functions
void rainbowRing(uint8_t hold) {
  uint16_t k;
  static uint16_t j;
    if(neoTimer.isTimerReady()){
      for(k=0; k<strip.numPixels(); k++) {
        strip.setPixelColor(k, Wheel((k+j) & 255));
      }
      strip.show();
      j++;
      neoTimer.startTimer(hold);
    }
    if(j == 256){
      j = 0;
    }
  }

uint32_t Wheel(byte WheelPos) {
  if(WheelPos < 85) {
   return strip.Color(WheelPos * 3, 255 - WheelPos * 3, 0);
  } else if(WheelPos < 170) {
   WheelPos -= 85;
   return strip.Color(255 - WheelPos * 3, 0, WheelPos * 3);
  } else {
   WheelPos -= 170;
   return strip.Color(0, WheelPos * 3, 255 - WheelPos * 3);
  }
}

// MQTT Adafruit.IO connections
void MQTT_connect() {
  int8_t ret;
  // Return if already connected.
  if (mqtt.connected()) {
    return;
  }
  Serial.print("Connecting to MQTT... ");
  while ((ret = mqtt.connect()) != 0) { // connect will return 0 for connected
    Serial.printf("Error Code %s\n",mqtt.connectErrorString(ret));
    Serial.printf("Retrying MQTT connection in 5 seconds...\n");
    mqtt.disconnect();
    delay(5000);  // wait 5 seconds and try again
  }
  Serial.printf("MQTT Connected!\n");
}
bool MQTT_ping() {
  static unsigned int last;
  bool pingStatus;
  if ((millis()-last)>200000) {
    Serial.printf("Pinging MQTT \n");
    pingStatus = mqtt.ping();
    if(!pingStatus) {
      Serial.printf("Disconnecting \n");
      mqtt.disconnect();
      }
      last = millis();
  }
  return pingStatus;
}

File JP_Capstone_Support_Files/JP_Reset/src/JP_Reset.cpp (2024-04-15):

/* 
 * Project JP_Reset
 * Author: JP Funk
 * Date: 04/13/2024
 * For comprehensive documentation and examples, please visit:
 * https://docs.particle.io/firmware/best-practices/firmware-template/
 */

// Include Particle Device OS APIs
#include "Particle.h"

// Let Device OS manage the connection to the Particle Cloud
SYSTEM_MODE(AUTOMATIC);

// Run the application and system concurrently in separate threads
SYSTEM_THREAD(ENABLED);

// Show system, cloud connectivity, and application logs over USB
// View logs with CLI using 'particle serial monitor --follow'
SerialLogHandler logHandler(LOG_LEVEL_INFO);

// setup() runs once, when the device is first turned on
void setup() {
  // Put initialization like pinMode and begin functions here
  Serial.begin(9600);
}

// loop() runs over and over again, as quickly as it can execute.
void loop() {
  //capture the time the board has been running
  int time = millis()/1000;
  
  //print the time from last reset
  Serial.print("I was reset ");
  Serial.print(time);
  Serial.println(" seconds ago.");
  Serial.println("Will you stop Dave. I am afraid.");
  delay(1000);
}

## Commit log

2024-04-12 JP Friday push for JP_Capstone starting files 04/12/2024
    [JP_Oracle_Fountain.fzz]
2024-04-17 JP Wednesday push for JP_Capstone files 04/17/2024
    [JP_Oracle_Fountain.fzz]
2024-04-18 JP Wednesday night push for JP_Capstone files 04/17/2024
    [JP_Oracle_Fountain.fzz]
2024-04-29 JP Monday 3D print JP_Capstone 3D files 04/29/2024
    [JP_Oracle_Base_Ring.SLDPRT, JP_Oracle_Base_Ring.STL, JP_Oracle_EBase.SLDPRT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]
2024-05-03 JP Friday updates JP_Capstone 05/03/2024
    [JP_Oracle_Fountain.fzz, JP_Oracle_FountainV1.fzz, JP_Oracle_Speaker_Ring.SLDPRT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]
2024-05-07 JP Monday code w/ EJ update JP_Capstone 05/06/2024
    [JP_Oracle_FountainV1.fzz, JP_Oracle_Top_Water_ShroudV2.SLDPRT, JP_Oracle_Top_Water_ShroudV2.STL]
2024-05-07 JP Tuesday update JP_Capstone 05/07/2024
    [JP_Oracle_Top_Water_ShroudV2.SLDPRT]
2024-05-09 JP Wednesday Late update JP_Capstone 05/08/2024
    [JP_Oracle_Assembly_Base.SLDASM, JP_Oracle_Assembly_Base.STL, JP_Oracle_Assembly_Ring.SLDASM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]
2024-05-10 JP Thursday night update JP_Capstone 05/09/2024
    [JP_BME_Holder.SLDPRT, JP_BME_Holder.STL]
2024-05-10 JP Friday 315 pm update JP_Capstone 05/10/2024
    [JP_BME_Holder.SLDPRT, JP_BME_Holder.STL, JP_Oracle_Top_Water_ShroudV2.SLDPRT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]
